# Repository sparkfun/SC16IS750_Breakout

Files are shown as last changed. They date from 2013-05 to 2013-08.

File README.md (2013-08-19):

SC16IS750 Breakout
=================

[SC16IS750 Breakout  
*Breakout Board for SC16IS750 I2C/SPI-to-UART IC (BOB-09981)*](https://www.sparkfun.com/products/9981)

The SC16IS750 converts I<sup>2</sup>C or SPI serial signals to a single-channel, high-performance UART.

Repository Contents
-------------------
* **/Hardware** - All Eagle design files (.brd, .sch)

License Information
-------------------
The hardware is released under [Creative Commons Share-alike 3.0](http://creativecommons.org/licenses/by-sa/3.0/).

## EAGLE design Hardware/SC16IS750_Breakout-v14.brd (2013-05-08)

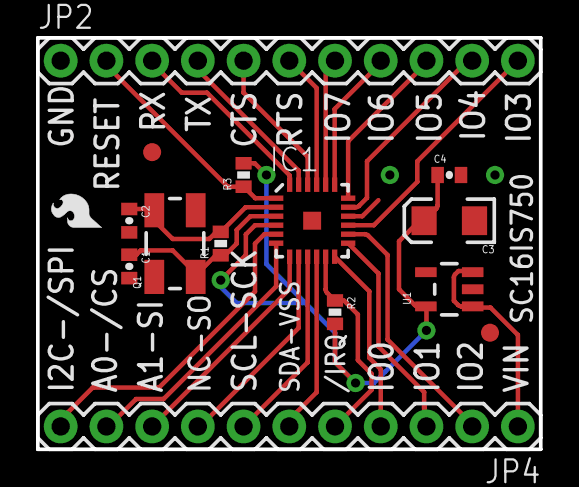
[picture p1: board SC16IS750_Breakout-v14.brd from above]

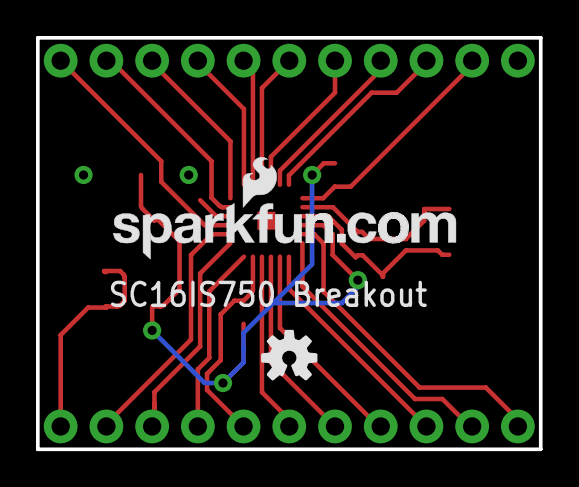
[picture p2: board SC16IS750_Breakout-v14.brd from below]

Board: 2 copper layers, 27.9 x 22.9 mm, 17 parts (2 on the bottom side), 25 nets.

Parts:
C1, C2: 18pF; 0402-CAP
C3: 10uF; EIA3216
C4: 0.1uF; 0402-CAP
IC1: SC16IS750; QFN-24
JP1: LOGO-SFENEW; SFE-NEW-WEBLOGO
JP2, JP4: M11PTH; 1X11
JP3: LOGO-SFESK; SFE-LOGO-FLAME
JP5, JP6: FIDUCIAL1X2; FIDUCIAL-1X2
Q1: 14.7456MHz; CRYSTAL-SMD-5X3
R1: 1M; 0402-RES
R2, R3: 1k; 0402-RES
U1: 3.3V; SOT23-5
U$1: OSHW-LOGOS; OSHW-LOGO-S

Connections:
/CTS: IC1.22, JP2.5
/IRQ: IC1.11, JP4.5, R2.1
/RTS: IC1.21, JP2.6
A0: IC1.6, JP4.10
A1: IC1.7, JP4.9
GND: C1.2, C2.2, C3.C, C4.2, IC1.16, JP2.1, U1.2
I2C: IC1.5, JP4.11
IO0: IC1.12, JP4.4
IO1: IC1.13, JP4.3
IO2: IC1.14, JP4.2
IO3: IC1.15, JP2.11
IO4: IC1.17, JP2.10
IO5: IC1.18, JP2.9
IO6: IC1.19, JP2.8
IO7: IC1.20, JP2.7
unnamed: C1.1, IC1.3, Q1.1, R1.1
unnamed: C2.1, IC1.2, Q1.3, R1.2
NC: IC1.8, JP4.8
RESET: IC1.1, JP2.2, R3.1
RX: IC1.24, JP2.3
SCL: IC1.9, JP4.7
SDA: IC1.10, JP4.6
TX: IC1.23, JP2.4
VDD: C3.A, C4.1, IC1.4, R2.2, R3.2, U1.5
VIN: JP4.1, U1.1, U1.3

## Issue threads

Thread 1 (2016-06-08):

Interrupt Pin (IRQ) not working

MohsinAnees, 2016-06-08:
I am facing problems using sc16is750 breakout board. I want to use the interrupt method mentioned in the datasheet. According to which, the IRQ pin should be active low whenever Rx or Tx pins are active, and an Interrupt should be generated.

But the IRQ pin remains high nonetheless. I have set up an external 1k ohm pull-up resistor as mentioned with 3.3v VDD.

Can someone help me out?

Galileo53, 2017-09-23:
There is a bug at the PCB routing:
All boards are missing the wire between the IRQ pin of the SC16IS750 and the IRQ connector at the board.
At the schematic, you can see that there are two different nets (/IRQ and IRQ) and therefore the router did not work as expected.
You can fix that problem by adding this wire manually.

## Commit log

2013-05-08 Initial file commit and README update
    [SC16IS750_Breakout-v14.brd, SC16IS750_Breakout-v14.sch]
2013-05-08 Added version number and description
    [SC16IS750_Breakout.brd, SC16IS750_Breakout.sch]
2013-05-13 Fixed board files
    [SC16IS750_Breakout.brd, SC16IS750_Breakout.sch]
2013-05-14 Fixed traces that were crooked
    [SC16IS750_Breakout.brd]
2013-05-14 Updated Package to "1:1" and rerouted traces directly away from IC
    [SC16IS750_Breakout.brd, SC16IS750_Breakout.sch]
2015-01-19 Updating to current board files
    [SC16IS750_Breakout.brd, SC16IS750_Breakout.sch, SparkFun_SC16IS750_Breakout-v13.brd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]

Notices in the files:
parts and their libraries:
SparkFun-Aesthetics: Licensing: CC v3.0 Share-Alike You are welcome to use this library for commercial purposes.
